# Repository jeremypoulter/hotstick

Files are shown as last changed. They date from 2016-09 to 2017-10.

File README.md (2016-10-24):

   
   

# Hotstick

An open-source hardware soldering station

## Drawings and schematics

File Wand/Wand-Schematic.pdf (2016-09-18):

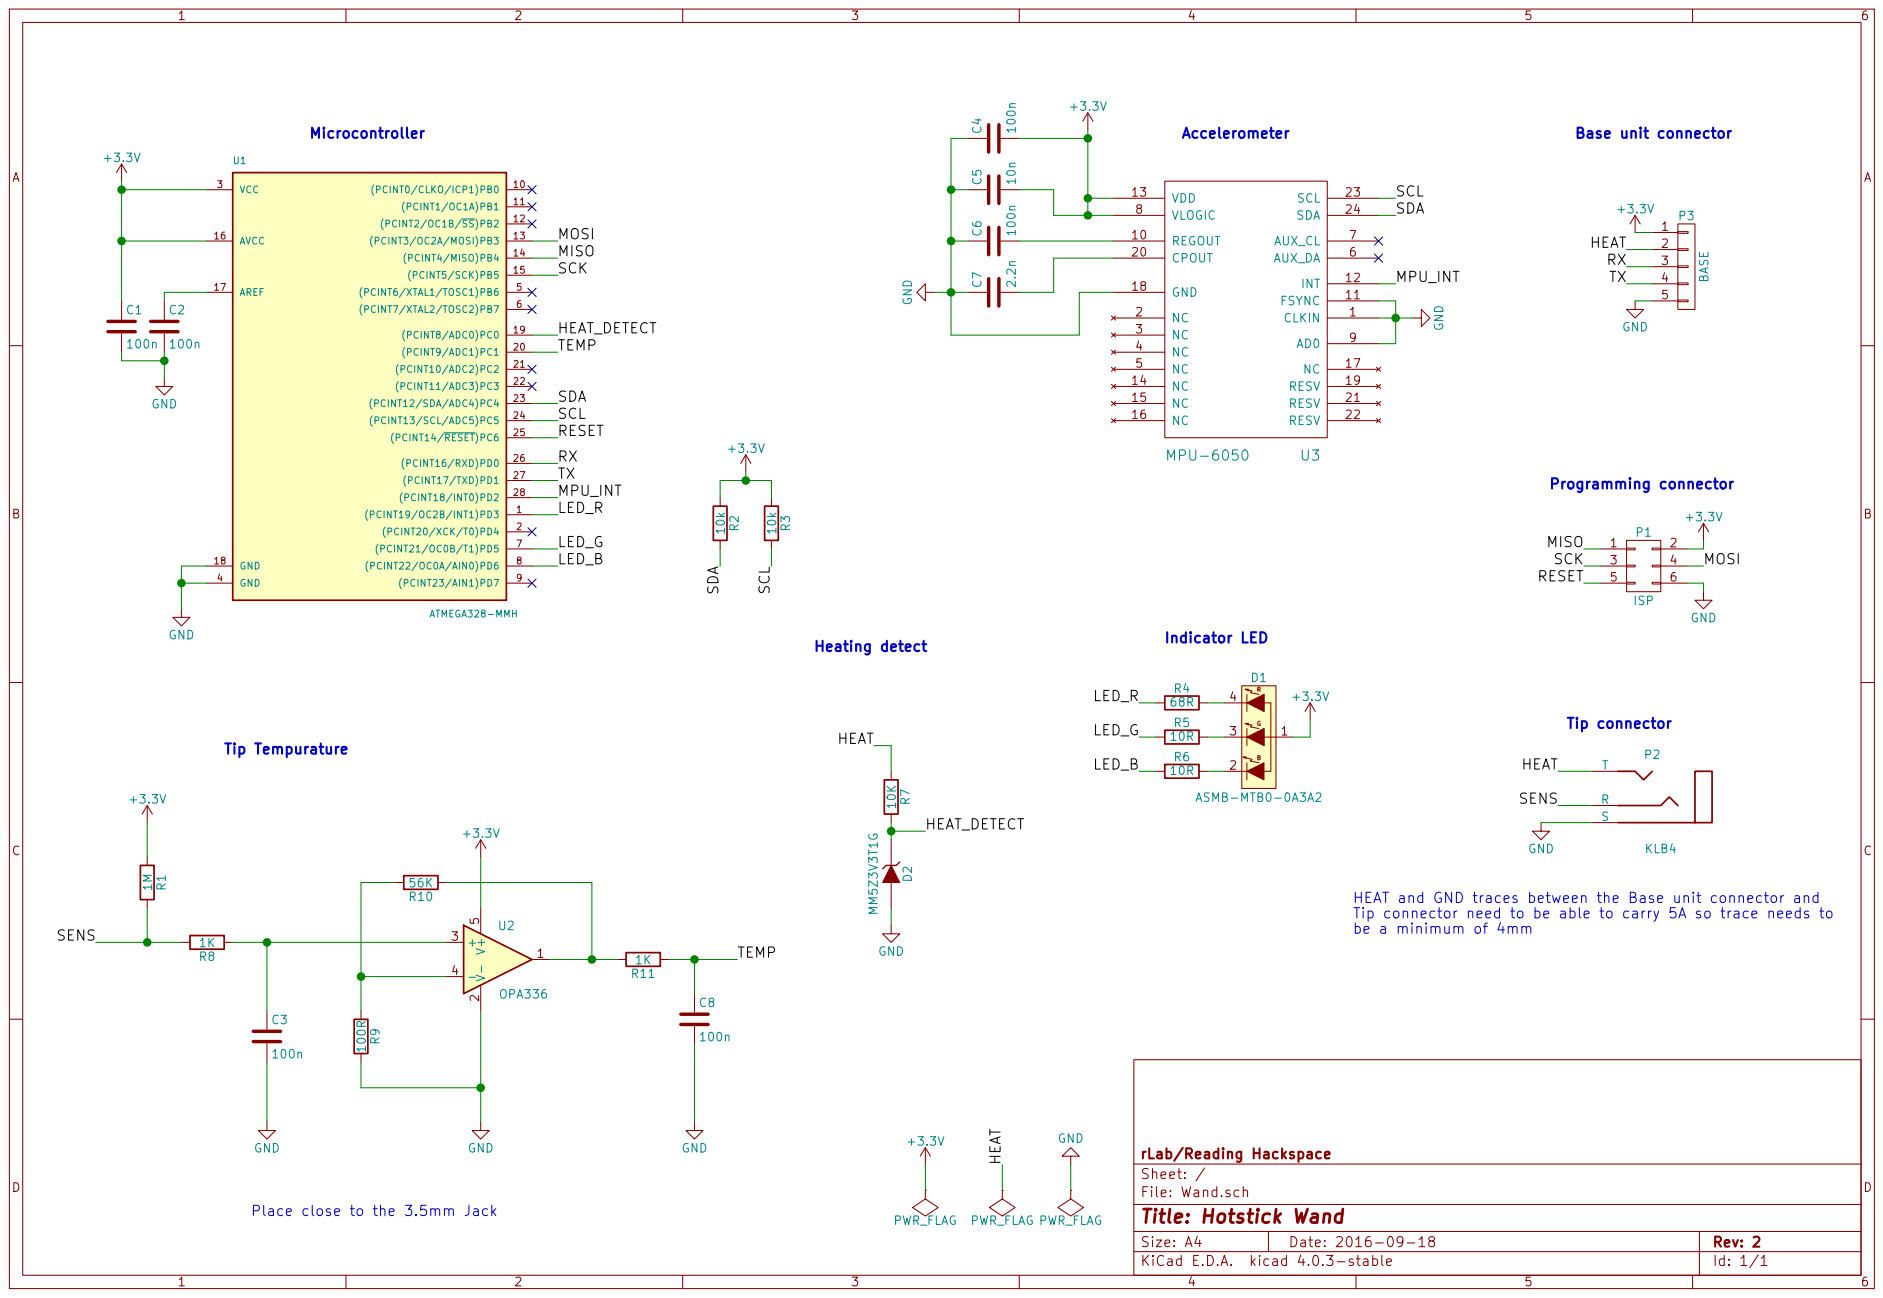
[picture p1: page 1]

SCL
MOSI GND GND HEAT SDA

HEAT and GND traces between the Base unit connector and
Tip connector need to be able to carry 5A so trace needs to be a minimum of 4mm

Id: 1/1 Title: Hotstick Wand

Place close to the 3.5mm Jack

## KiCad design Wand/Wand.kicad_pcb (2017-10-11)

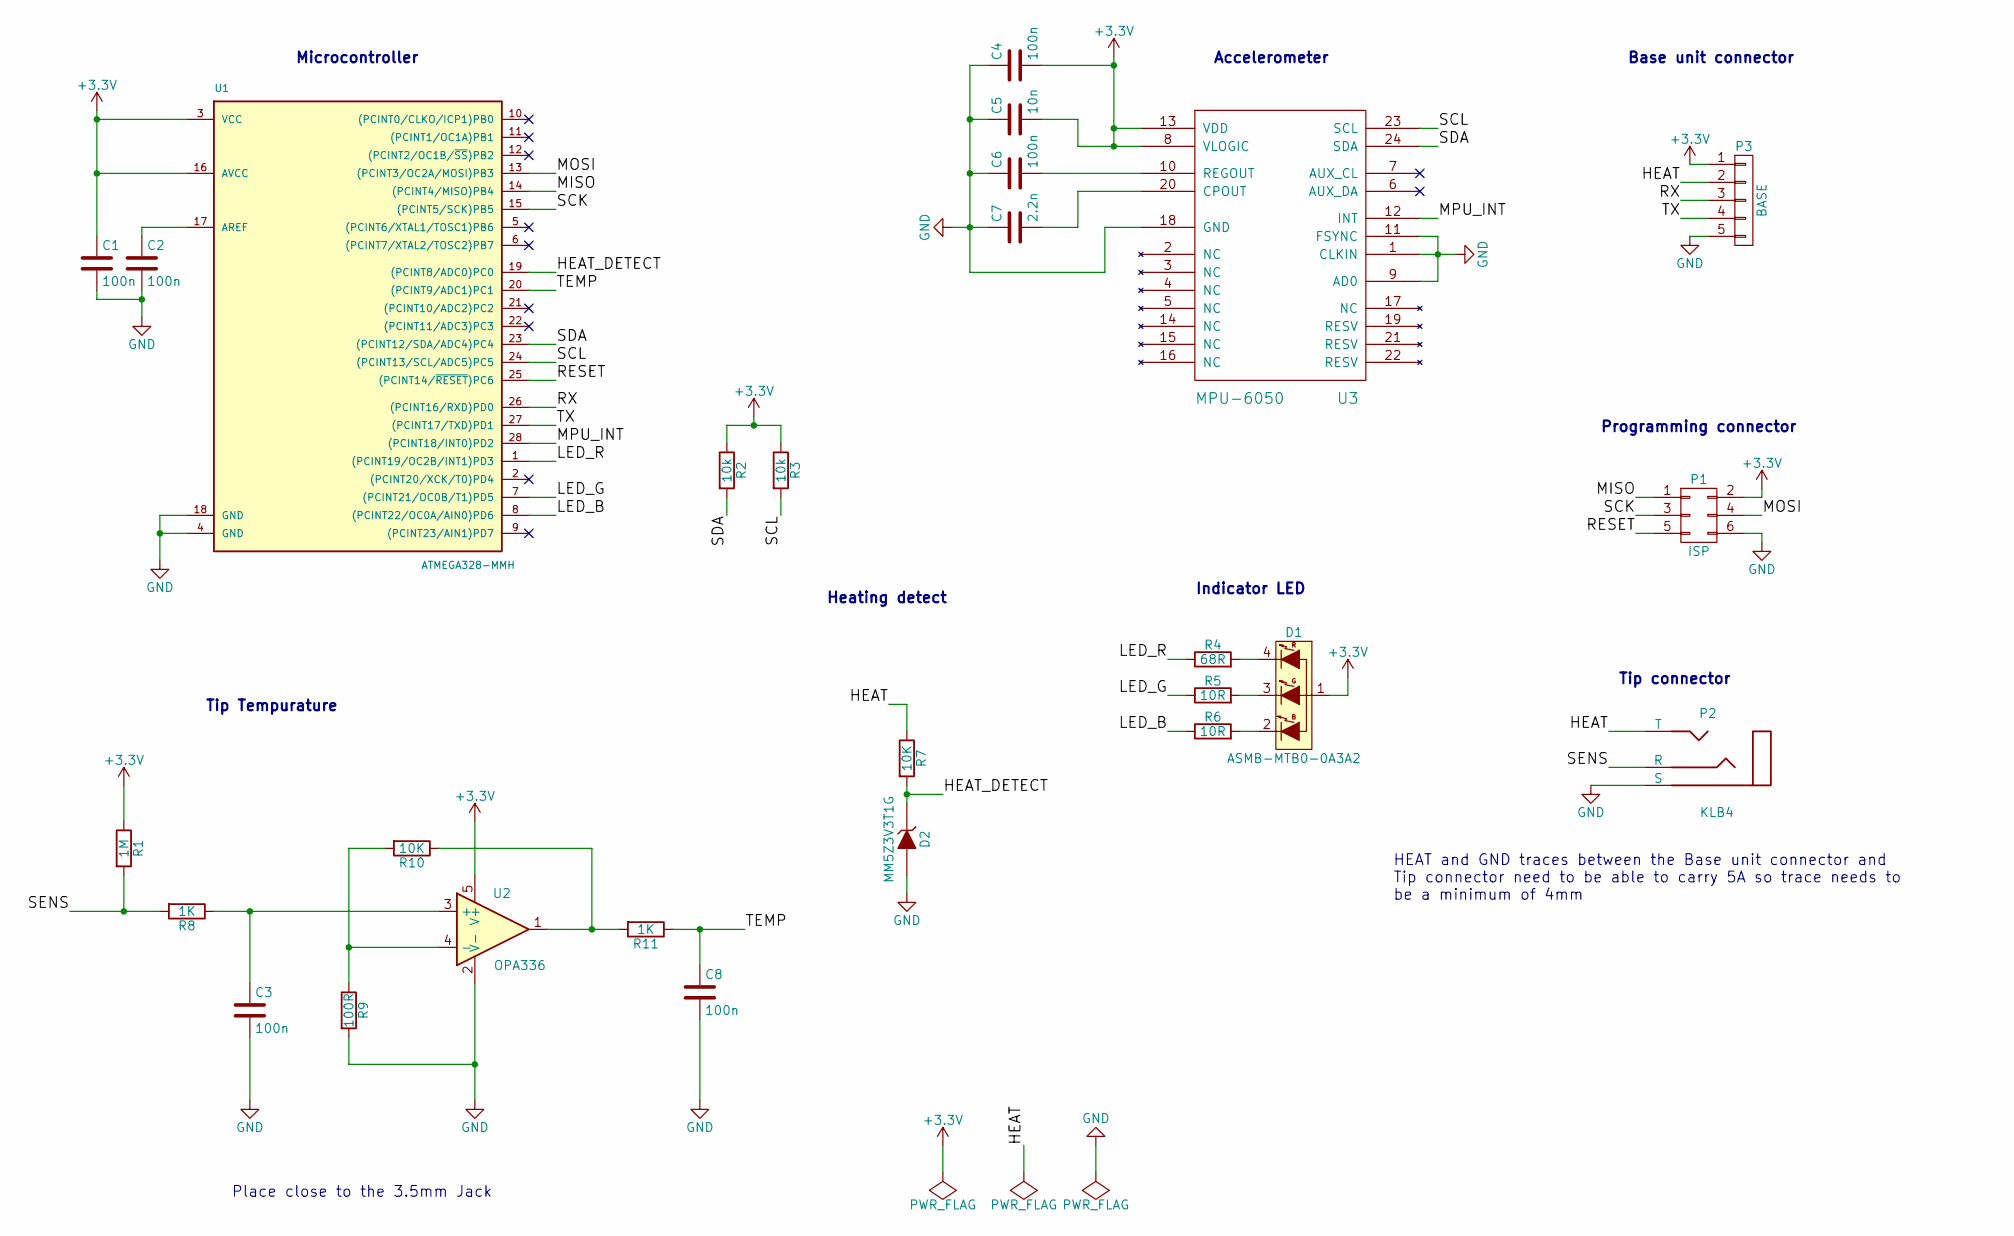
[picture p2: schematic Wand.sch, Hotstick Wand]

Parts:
C1, C2, C3, C4, C6, C8: 100n; C_0402
C5: 10n; C_0402
C7: 2.2n; C_0402
D1: ASMB-MTB0-0A3A2; Tri-Colour_LED
D2: MM5Z3V3T1G; SOD-523
P1: ISP; ISP_pads_2x3
P2: KLB4; Jack_3.5mm_KLB
P3: BASE; Base_Connector
R1: 1M; R_0402
R2, R3: 10k; R_0402
R4: 68R; R_0402
R5, R6: 10R; R_0402
R7, R10: 10K; R_0402
R8, R11: 1K; R_0402
R9: 100R; R_0402
U1: ATMEGA328-MMH; QFN-28-1EP_4x4mm_Pitch0.45mm
U2: OPA336; SOT-23-5
U3: MPU-6050

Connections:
+3V3: C1.1, C4.2, C5.2, D1.1, P1.2, P3.1, R1.1, R2.1, R3.1, U1.3 (VCC), U1.16 (AVCC), U2.5 (V+), U3.8 (VLOGIC), U3.13 (VDD)
/HEAT: P2.T, P3.2, R7.1
/HEAT_DETECT: D2.1 (K), R7.2, U1.19 ((PCINT8/ADC0)PC0)
/LED_B: R6.1, U1.8 ((PCINT22/OC0A/AIN0)PD6)
/LED_G: R5.1, U1.7 ((PCINT21/OC0B/T1)PD5)
/LED_R: R4.1, U1.1 ((PCINT19/OC2B/INT1)PD3)
/MISO: P1.1, U1.14 ((PCINT4/MISO)PB4)
/MOSI: P1.4, U1.13 ((PCINT3/OC2A/MOSI)PB3)
/MPU_INT: U1.28 ((PCINT18/INT0)PD2), U3.12 (INT)
/RESET: P1.5, U1.25 ((PCINT14/~RESET~)PC6)
/RX: P3.3, U1.26 ((PCINT16/RXD)PD0)
/SCK: P1.3, U1.15 ((PCINT5/SCK)PB5)
/SCL: R3.2, U1.24 ((PCINT13/SCL/ADC5)PC5), U3.23 (SCL)
/SDA: R2.2, U1.23 ((PCINT12/SDA/ADC4)PC4), U3.24 (SDA)
/SENS: P2.R, R1.2, R8.2
/TEMP: C8.1, R11.1, U1.20 ((PCINT9/ADC1)PC1)
/TX: P3.4, U1.27 ((PCINT17/TXD)PD1)
GND: C1.2, C2.2, C3.2, C4.1, C5.1, C6.1, C7.1, C8.2, D2.2 (A), P1.6, P2.S, P3.5, R9.2, U1.4 (GND), U1.18 (GND), U2.2 (V-), U3.1 (CLKIN), U3.9 (AD0), U3.11 (FSYNC), U3.18 (GND)
unnamed: C2.1, U1.17 (AREF)
unnamed: C3.1, R8.1, U2.3 (+)
unnamed: C6.2, U3.10 (REGOUT)
unnamed: C7.2, U3.20 (CPOUT)
unnamed: D1.2 (B), R6.2
unnamed: D1.3 (G), R5.2
unnamed: D1.4 (R), R4.2
unnamed: R10.1, R11.2, U2.1
unnamed: R9.1, R10.2, U2.4 (-)

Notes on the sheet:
Tip connector
Programming connector
Base unit connector
Accelerometer
Microcontroller
Indicator LED
Place close to the 3.5mm Jack
Tip Tempurature
HEAT and GND traces between the Base unit connector and Tip connector need to be able to carry 5A so trace needs to be a minimum of 4mm
Heating detect

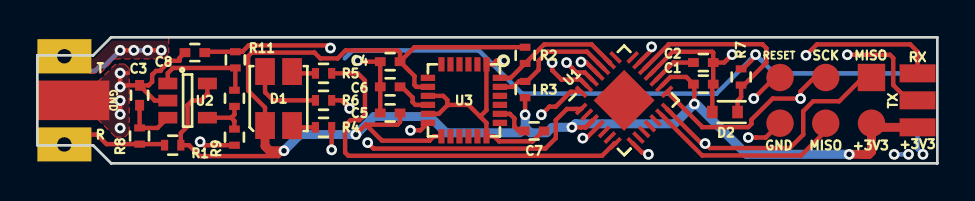
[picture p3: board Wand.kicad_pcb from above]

Board: 4 copper layers, 50.0 x 7.0 mm, 27 parts (1 on the bottom side), 27 nets.

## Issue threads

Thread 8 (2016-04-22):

Difficult to solder 3.5mm jack

jeremypoulter, 2016-04-22:
Need to add castellations down the sides

jeremypoulter, 2016-04-22:
- http://electronics.stackexchange.com/questions/78094/how-to-specify-castellations-in-gerber-files

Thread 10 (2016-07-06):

Move vias from under MPU 6050

jeremypoulter, 2016-07-06:
The MPU 6050 has a pad on the bottom so can be shorted if solder mask fails

jeremypoulter, 2016-09-18:
Done

Closed 2016-09-18.

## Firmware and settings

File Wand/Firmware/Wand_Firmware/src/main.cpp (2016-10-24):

// rLab Hotstick Wand Firmware
//
// Jeremy Poulter

#include <Arduino.h>
#include <ArduinoJson.h>

#include "I2Cdev.h"

#include "MPU6050_6Axis_MotionApps20.h"
//#include "MPU6050.h" // not necessary if using MotionApps include file

// Arduino Wire library is required if I2Cdev I2CDEV_ARDUINO_WIRE implementation
// is used in I2Cdev.h
#if I2CDEV_IMPLEMENTATION == I2CDEV_ARDUINO_WIRE
    #include "Wire.h"
#endif

#define LED_RED         3
#define LED_GREEN       5
#define LED_BLUE        6

#define HEAT_DETECT_PIN A0
#define TEMP_PIN        A1
#define INTERRUPT_PIN   2  // use pin 2 on Arduino Uno & most boards

#define SEND_STATE_TIME (1000/25) // Update the base at 25 Hz
#define TIP_TEMP_READ_DELAY 5 // Time to wait after heat is turned off

#define TEMP_ERROR_HEATER_ON  -1.0
#define TEMP_ERROR_NO_TIP     -2.0

#define JSON_BUFFER_SIZE 200

// MPU control/status vars
MPU6050 mpu;
volatile bool mpuInterrupt = false;     // indicates whether MPU interrupt pin has gone high
bool dmpReady = false;  // set true if DMP init was successful
uint8_t mpuIntStatus;   // holds actual interrupt status byte from MPU
uint8_t devStatus;      // return status after each device operation (0 = success, !0 = error)
uint16_t packetSize;    // expected DMP packet size (default is 42 bytes)
uint16_t fifoCount;     // count of all bytes currently in FIFO
uint8_t fifoBuffer[64]; // FIFO storage buffer

// orientation/motion vars
Quaternion q;           // [w, x, y, z]         quaternion container
VectorFloat gravity;    // [x, y, z]            gravity vector
float ypr[3];           // [yaw, pitch, roll]   yaw/pitch/roll container and gravity vector

unsigned long sendStateTimeout = 0;
unsigned long tipTempValidAfter = 0;
int lastHeatState = LOW;

double yaw = 0.0;
double pitch = 0.0;
double roll = 0.0;

// Temperature related functions
double readTempInt();
double readTempTip(double tempInt);

// MPU/DMP related stuff
void mpu_setup();
void mpu_read();
void dmpDataReady();

// LED control
void led_setup();
void led(int red, int green, int blue);

void setup()
{
  // Initialise the serial
  Serial.begin(38400);

  led_setup();
  mpu_setup();

  // Set the initial state of the LED to Yellow
  led(255, 255, 0);

  // We are using the Internal refernce voltage for the ADC
  analogReference(INTERNAL);

  lastHeatState = digitalRead(HEAT_DETECT_PIN);
  tipTempValidAfter = millis() + TIP_TEMP_READ_DELAY;
}

void loop()
{
  // Read the MPU
  mpu_read();

  // Has the state of the Heat detect pin changed
  int heatState = digitalRead(HEAT_DETECT_PIN);
  if(lastHeatState != heatState) {
    lastHeatState = heatState;
    tipTempValidAfter = millis() + TIP_TEMP_READ_DELAY;
  }

  // Read any message from the Wand
  if(Serial.available())
  {
    char start = Serial.peek();
    if('{' == start)
    {
      char data[JSON_BUFFER_SIZE];
      int read = Serial.readBytesUntil('}', data, JSON_BUFFER_SIZE);
      if(read + 2 < JSON_BUFFER_SIZE)
      {
        data[read++] = '}';
        data[read++] = '\0';
        Serial.print(F("Got "));
        Serial.print(data);
        Serial.println(F(" from Base"));

        StaticJsonBuffer<JSON_BUFFER_SIZE> jsonBuffer;

        JsonObject& msg = jsonBuffer.parseObject(data);

        // Check to see if we got an LED message
        if(msg["led"].success()) {
          led(msg["led"][0], msg["led"][1], msg["led"][2]);
        }
      }
    } else {
      Serial.read();
    }
  }

  // Do we need to send a status updates
  if(millis() >= sendStateTimeout)
  {
    StaticJsonBuffer<JSON_BUFFER_SIZE> jsonBuffer;

    // We want to send status updates exactly at the same interval so sent the next
    // timeout now
    sendStateTimeout = millis() + SEND_STATE_TIME;

    // Read the temp
    double tempint = readTempInt();
    double temptip = readTempTip(tempint);

    JsonObject& state = jsonBuffer.createObject();
    state["temptip"] = temptip;
    state["tempint"] = tempint;
    state["yaw"] = yaw;
    state["pitch"] = pitch;
    state["roll"] = roll;

    state.printTo(Serial);
    Serial.println("");
  }
}

void led(int red, int green, int blue)
{
  analogWrite(LED_RED, 255 - red);
  analogWrite(LED_GREEN, 255 - green);
  analogWrite(LED_BLUE, 255 - blue);
}

void led_setup()
{
  pinMode(LED_RED, OUTPUT);
  pinMode(LED_GREEN, OUTPUT);
  pinMode(LED_BLUE, OUTPUT);
}

double readTempTip(double intTemp)
{
  if(HIGH == digitalRead(HEAT_DETECT_PIN) || tipTempValidAfter > millis()) {
    return TEMP_ERROR_HEATER_ON;
  }

  double tempAdc = (double)analogRead(TEMP_PIN);
  if(tempAdc >= 1022.9) {
    return TEMP_ERROR_NO_TIP;
  }

//  return intTemp + 16.22 + tempAdc * 0.61;
  return 16.913 + (tempAdc * 0.61) + (-0.0002 * pow(tempAdc, 2));
}

double readTempInt()
{
  int16_t rawTemp = mpu.getTemperature();
  return (rawTemp/340.)+36.53;
}

void dmpDataReady() {
    mpuInterrupt = true;
}

void mpu_setup()
{
  // join I2C bus (I2Cdev library doesn't do this automatically)
  #if I2CDEV_IMPLEMENTATION == I2CDEV_ARDUINO_WIRE
    Wire.begin();
    Wire.setClock(400000); // 400kHz I2C clock. Comment this line if having compilation difficulties
  #elif I2CDEV_IMPLEMENTATION == I2CDEV_BUILTIN_FASTWIRE
    Fastwire::setup(400, true);
  #endif

  // initialize device
  Serial.println(F("Initializing I2C devices..."));
  mpu.initialize();
  pinMode(INTERRUPT_PIN, INPUT);

  // verify connection
  Serial.println(F("Testing device connections..."));
  Serial.println(mpu.testConnection() ? F("MPU6050 connection successful") : F("MPU6050 connection failed"));

  // load and configure the DMP
  Serial.println(F("Initializing DMP..."));
  devStatus = mpu.dmpInitialize();

  // supply your own gyro offsets here, scaled for min sensitivity
  mpu.setXGyroOffset(220);
  mpu.setYGyroOffset(76);
  mpu.setZGyroOffset(-85);
  mpu.setZAccelOffset(1788); // 1688 factory default for my test chip

  // make sure it worked (returns 0 if so)
  if (devStatus == 0) {
    // turn on the DMP, now that it's ready
    Serial.println(F("Enabling DMP..."));
    mpu.setDMPEnabled(true);

    // enable Arduino interrupt detection
    Serial.println(F("Enabling interrupt detection (Arduino external interrupt 0)..."));
    attachInterrupt(digitalPinToInterrupt(INTERRUPT_PIN), dmpDataReady, RISING);
    mpuIntStatus = mpu.getIntStatus();

    // set our DMP Ready flag so the main loop() function knows it's okay to use it
    Serial.println(F("DMP ready! Waiting for first interrupt..."));
    dmpReady = true;

    // get expected DMP packet size for later comparison
    packetSize = mpu.dmpGetFIFOPacketSize();
  } else {
    // ERROR!
    // 1 = initial memory load failed
    // 2 = DMP configuration updates failed
    // (if it's going to break, usually the code will be 1)
    Serial.print(F("DMP Initialization failed (code "));
    Serial.print(devStatus);
    Serial.println(F(")"));
  }
}

void mpu_read()
{
    // if programming failed, don't try to do anything
    if (!dmpReady) return;

    // wait for MPU interrupt or extra packet(s) available
    while (!mpuInterrupt && fifoCount < packetSize) {
        // other program behavior stuff here
        // .
        // .
        // .
        // if you are really paranoid you can frequently test in between other
        // stuff to see if mpuInterrupt is true, and if so, "break;" from the
        // while() loop to immediately process the MPU data
        // .
        // .
        // .
    }

    // reset interrupt flag and get INT_STATUS byte
    mpuInterrupt = false;
    mpuIntStatus = mpu.getIntStatus();

    // get current FIFO count
    fifoCount = mpu.getFIFOCount();

    // check for overflow (this should never happen unless our code is too inefficient)
    if ((mpuIntStatus & 0x10) || fifoCount == 1024) {
        // reset so we can continue cleanly
        mpu.resetFIFO();
        Serial.println(F("FIFO overflow!"));

    // otherwise, check for DMP data ready interrupt (this should happen frequently)
    } else if (mpuIntStatus & 0x02) {
        // wait for correct available data length, should be a VERY short wait
        while (fifoCount < packetSize) fifoCount = mpu.getFIFOCount();

        // read a packet from FIFO
        mpu.getFIFOBytes(fifoBuffer, packetSize);

        // track FIFO count here in case there is > 1 packet available
        // (this lets us immediately read more without waiting for an interrupt)
        fifoCount -= packetSize;

        // display Euler angles in degrees
        mpu.dmpGetQuaternion(&q, fifoBuffer);
        mpu.dmpGetGravity(&gravity, &q);
        mpu.dmpGetYawPitchRoll(ypr, &q, &gravity);
        yaw = (ypr[0] * 180/M_PI);
        pitch = (ypr[1] * 180/M_PI);
        roll = (ypr[2] * 180/M_PI);
    }
}

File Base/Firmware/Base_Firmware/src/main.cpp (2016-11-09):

#include <Arduino.h>
#include <ArduinoJson.h>

#define NOT_ENABLE_PIN  2
#define HEATER_ON       LOW
#define HEATER_OFF      HIGH

// If we don't receive a message in an ammount of time go to a fail safe mode
#define COMMS_TIMEOUT   200

// The max tme to leave the heater on for
#define HEATER_ON_TIME  500

// Min time to leave the heater off for, to read the temp
#define HEATER_OFF_TIME 100

#define JSON_BUFFER_SIZE 200

// Heater state, HIGH is off, LOW is on
int heaterState = HEATER_OFF;

double temptip = 0.0;
double tempint = 0.0;
double yaw = 0.0;
double pitch = 0.0;
double roll = 0.0;

unsigned long messageTimeout = 0;
unsigned long heaterOnTimeout = 0;
unsigned long heaterOffTimeout = 0;

double tempTarget = 350.0;

void setup() {
  Serial.begin(115200);
  Serial1.begin(38400);

  Serial.println("Hotstick base station");

  pinMode(NOT_ENABLE_PIN, OUTPUT);
  digitalWrite(NOT_ENABLE_PIN, heaterState);
}

void loop()
{
  // Read any message from the Wand
  if(Serial1.available())
  {
    char start = Serial1.peek();
    if('{' == start)
    {
      char data[JSON_BUFFER_SIZE];
      int read = Serial1.readBytesUntil('}', data, JSON_BUFFER_SIZE);
      if(read+2 < JSON_BUFFER_SIZE)
      {
        data[read++] = '}';
        data[read++] = '\0';

/*
        Serial.print("Got ");
        Serial.print(data);
        Serial.println(" from Wand");
*/

        StaticJsonBuffer<JSON_BUFFER_SIZE> jsonBuffer;

        JsonObject& msg = jsonBuffer.parseObject(data);

        // tip temp will be < 0 if the heater is on
        if(msg["temptip"].success() &&
           msg["tempint"].success() &&
           msg["yaw"].success() &&
           msg["pitch"].success() &&
           msg["roll"].success())
        {
          double readtemptip = msg["temptip"];
          if(readtemptip > 0.0) {
            temptip = readtemptip;
          }
          tempint = msg["tempint"];
          yaw = msg["yaw"];
          pitch = msg["pitch"];
          roll = msg["roll"];

/*
          Serial.print("temptip = ");
          Serial.print(temptip);
          Serial.print(", ");
          Serial.println(readtemptip);
          Serial.print("tempint = ");
          Serial.println(tempint);
          Serial.print("yaw = ");
          Serial.println(yaw);
          Serial.print("pitch = ");
          Serial.println(pitch);
          Serial.print("roll = ");
          Serial.println(roll);
*/
          Serial.print(temptip);
          Serial.print(",");
          Serial.print(readtemptip);
          Serial.print(",");
          Serial.print(tempint);
          Serial.print(",");
          Serial.print(yaw);
          Serial.print(",");
          Serial.print(pitch);
          Serial.print(",");
          Serial.print(roll);
          Serial.print(",");
          Serial.println(heaterState);

          messageTimeout = millis() + COMMS_TIMEOUT;
        }
      } else {
        Serial.println("Serial buffer full");
      }
    } else {
      Serial1.read();
    }
  }

  if(millis() < messageTimeout)
  {
    if(HEATER_OFF == heaterState)
    {
      // Heater is off

      // Turn on if the off timer has expired and the tip temp is lower than the
      // required temp
      if(temptip >= tempTarget)
      {
        Serial1.print("{\"led\":[0,255,0]}");
      }
      else if(millis() > heaterOffTimeout)
      {
        heaterState = HEATER_ON;
        digitalWrite(NOT_ENABLE_PIN, heaterState);
        heaterOnTimeout = millis() + HEATER_ON_TIME;

        Serial1.print("{\"led\":[255,0,0]}");
      }
    }
    else
    {
      // Heater is on

      // Turn it off if the on timer has expired or the target temp has been reached
      if(millis() > heaterOnTimeout || temptip >= tempTarget)
      {
        heaterState = HEATER_OFF;
        digitalWrite(NOT_ENABLE_PIN, heaterState);
        heaterOffTimeout = millis() + HEATER_OFF_TIME;
        Serial1.print("{\"led\":[0,0,255]}");
      }
    }
  }
  else
  {
    // No data from Wand, make sure the heater is off
    heaterState = HEATER_OFF;
    digitalWrite(NOT_ENABLE_PIN, heaterState);
  }
}

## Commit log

2016-07-15 Set the board type
2016-09-18 Initial re-layout of the Hotstick Wand.
    - Fixed tip connector
    - Fixed the vias under the MPU-6050
    - Changed to use an op-amp to read the tip temp
    [Wand.kicad_pcb, Wand.sch]
2016-09-18 Added copper fills
    [Wand.kicad_pcb]
2016-09-18 Tidy up of the silk screen
    [Wand.kicad_pcb]
2016-09-18 3D shape tweaks
    [Wand.kicad_pcb]
2016-09-18 Tweaks to adjust pads on tip jack for castellations and increased the gap between the ground and tip/ring pins
    [Wand.kicad_pcb]
2016-09-18 A few final tweaks
    [Wand.kicad_pcb, Wand.sch]
2016-09-18 Production files
    [Wand-B.Mask.gbr, Wand-B.Paste.gbp, Wand-B.Power.Cu.gbl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]
2016-10-16 Updated resister values with those from the prototype
    [Wand.sch]
2016-10-16 Type D thermocouple reference values in an Excel
    [D Type Thermocouple.xlsx]
2016-10-19 Synced with schematic
    [Wand.kicad_pcb]
2016-10-19 Initial comms
    Implemented reading the temp and sending it to the base.
    Implemented receiving led message from base
2016-10-19 Change LED when heater is on/off
2016-10-19 Better name for the heater status
2016-10-20 Build for the actual prototype
2016-10-24 PlatformIO board definitions for the Wand
2016-10-24 Install the board files during CI
    Should fix build issue
2016-10-24 Moved to a .ino file
    For some reason Platform IO would not upload to my Mega so moved to a .ino file. Also fixed some logic errors and reading of the JSON.
    [main.cpp, src.ino]
2016-10-24 Fixed reading of the JSON message from the base
    [main.cpp]
2016-10-28 Changed back to main.cpp to fix CI
    [main.cpp]
2016-11-09 Tweaks to make the heater code a bit more readable
2017-10-11 Updated as per recommendations from PCB Way (0.25 mm gap between edge and traces.
    [Wand.kicad_pcb]
